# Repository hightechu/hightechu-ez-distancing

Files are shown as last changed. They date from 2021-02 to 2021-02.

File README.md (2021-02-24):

# EZ Distancing




## EZ Distancing is an Arduino project that encourages users to follow social distancing protocols
This Arduino project uses 2 Passive Infrared Sensors (PIR) and 2 Ultrasonic Distance Sensors to detect if another person is within the users 2 meter social distancing bubble. If the device detects that a person is within a 2 meter radius of the user, it will alert them, letting them know that they should move away to maintain social distancing. If the person is maintaining their social distancing, it will let them know that they are the recommended distance away from others.

## How it works

- The 2 Ultrasonic sensors measure the distance of the target object by emitting ultrasonic sound waves. The sensor determines the distance of an object by calculating the time it takes to send and receive a pulse.

- The Passive Infrared sensors measure the amount of IR light (or heat) that an object gives off. These sensors are being used to differentiate between non-living and living things. 

- When the device detects that another person is too close, it will give the user alerts via an OLED or LCD display and a LED/vibration motor.

- The DIP switches allow the user to choose which alerts they want to receive. Individual components can be turned off, like the LED or vibration motor.

## Component Usage

- Arduino Uno:
Microcontroller that will be handling all of the code, data, and inputs/outputs

- OLED or LCD Screen:
To give the user different text based alerts

- Distance Sensors:
Ultrasonic sensor that measures distance from 2cm - 400cm

- Motion Sensors:
Passive Infrared Sensor that measures 6 to 7 meters at 110 degrees

- Vibration Motor:
Vibration to physically alert the user 

- LED:
Light to visually alert the user 

- DIP switches:
This is to turn off any specific components, such as the LCD, OLED display, or vibration motor. This component is optional and wont require any changes to the code.

- Switch:
This will be used to turn the whole system on or off.

## Components List

#### All of the components used can be easily sourced on Amazon for about $100USD or $130 CAD
  - 1x Arduino R3 | [Arduino](https://store.arduino.cc/usa/arduino-uno-rev3) | [Amazon](https://amzn.to/39Mofgh) | [Arduino Datasheet](https://github.com/hightechu/hightechu-ez-distancing/blob/readme-updates/Datasheets/Arduino%20Datasheet.pdf)
  - 1x OLED Display | [Amazon](https://amzn.to/3oUkh9T) |  [OLED Datasheet](https://github.com/hightechu/hightechu-ez-distancing/blob/readme-updates/Datasheets/OLED%20Datasheet.pdf) This Diplay is also an option: [Adafruit](https://www.adafruit.com/product/1447)
  - 2x PIR Sensors | [Amazon](https://amzn.to/3jdQJ5E) | [Digikey](https://www.digikey.ca/en/products/detail/parallax-inc/555-28027/1774435?productid=1774435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) | [PIR Datasheet](https://github.com/hightechu/hightechu-ez-distancing/blob/readme-updates/Datasheets/PIR%20Datasheet.pdf)
  - 2x Ultrasonic Distance Sensors | [Amazon](https://amzn.to/3cDDKZL) | [Digikey](https://www.digikey.ca/en/products/detail/parallax-inc/28015/1774419?productid=1774419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) | [Ultrasonic Datasheet](https://github.com/hightechu/hightechu-ez-distancing/blob/readme-updates/Datasheets/Ultrasonic%20Datasheet.pdf)
  - 1x Vibration Motor | [Amazon](https://amzn.to/2O4mnXT) | [Banggood](https://usa.banggood.com/Vibration-Motor-Module-Mini-Flat-Vibrating-DC-Motor-p-1334091.html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)
  - 1x LED Light | [Amazon](https://amzn.to/2MWNaoA) | Any basic LED light will work
  - 1x 330 Ohm Resistor | [Amazon](https://amzn.to/2MNKfhM) | Any 330 ohm resistor will work
  - 1x Power Switch | [Amazon](https://amzn.to/2O3LQ3I) | This can be any type of basic switch
  - 1x DIP Switches | [Amazon](https://amzn.to/3je81Q0) | For the dipswitches, you can also use multiple normal switches
  - 1x Arduino 9v Battery Clip | [Amazon](https://amzn.to/3aAL9Gw) | This needs to be a 9V battery clip to 5.5mm barrel jack adapter
  - 1x 9 Volt Battery | [Amazon](https://amzn.to/36EQhbG) | Any 9V battery will work

 ## Diagrams | [See the Digital Circuit Here](https://www.tinkercad.com/things/4oZ3T0bb2it)
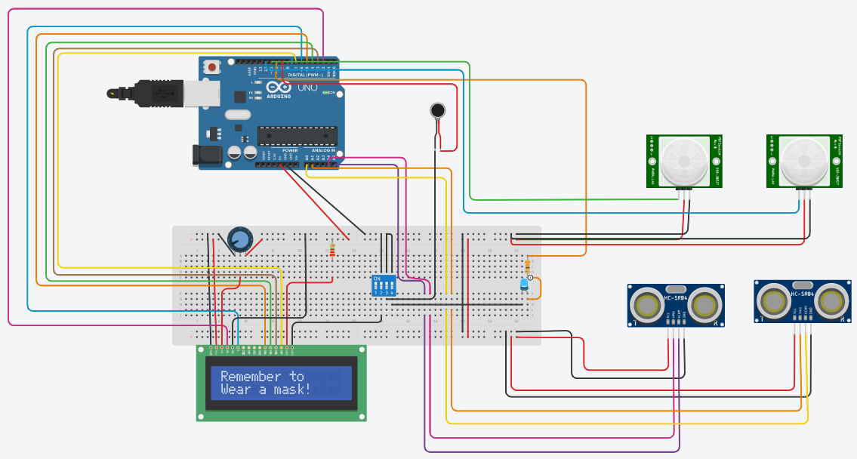
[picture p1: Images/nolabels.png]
EZ Social Distancing

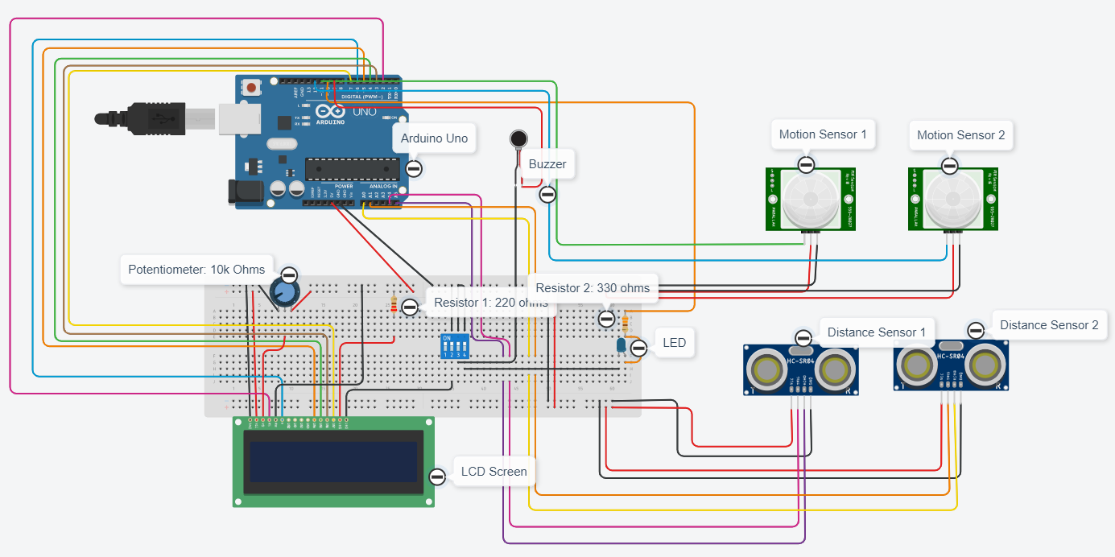
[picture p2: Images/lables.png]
EZ Social Distancing Labels


## Schematic | Drawn using [Fritzing](https://fritzing.org/)
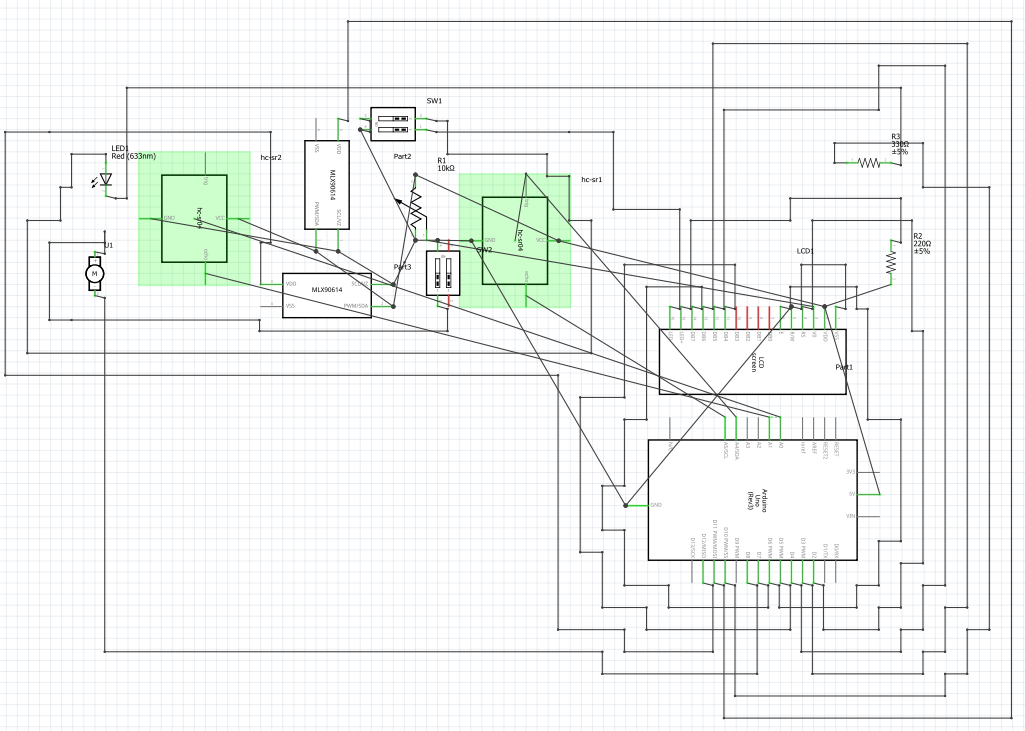
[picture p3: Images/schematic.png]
EZ Social Distancing Schematic


## Wiring List
### LCD (Note: This is for the Arduino 16x2 display. This will need the [LCD specific code](https://github.com/hightechu/hightechu-ez-distancing/blob/development/Arduino%20Code/EZ%20Social%20Distance%20(LCD16x2)/EZ%20Social%20Distance%20(LCD16x2).ino))
- GND → Ground
- VCC → Positive
- V0 → potentiometer wiper pin → Positive (5V) + Ground
- RS → Digital 2
- R/W → Ground
- E → Digital 6
- D0 → Nothing
- D1 → Nothing
- D2 → Nothing
- D3 → Nothing
- D4 → Digital 5
- D5 → Digital 4
- D6 → Digital 3
- D7 → Digital 7
- A (Anode) → 220 Ohm resistor → Positive (5V)
- K (Cathode) → Ground

### OR

### OLED (Note: This wiring list is for the OLED. This will need the [OLED specific code](https://github.com/hightechu/hightechu-ez-distancing/blob/development/Arduino%20Code/EZ%20Social%20Distance%20(OLED)/EZ%20Social%20Distance%20(OLED).ino))
- GND → Dipswitch 2 → Ground
- VCC → Positive (5V)
- SCK → Analog 4
- SDA → Analog 5

### LED:
- Cathode (Long Side) → Dipswitch 3 → Ground
- Anode (Short Side) → 330 Ohm resistor → Digital 10

### Vibration Motor:
- GND → Ground
- VCC → Positive (5V)
- IN → Digital 9

### DIP switches:
- Switch 1 (LED Resistor) → Digital 10 (This dipswitch is to turn the LED alerts on/off)
- Switch 2 (Vibration Motor In) → Digital 9 (This dipswitch is to turn the vibration alerts on/off)

### PIR Sensor 1:
- Signal → Digital 11
- Power → Positive (5V)
- GND → Ground

### PIR Sensor 2:
- Signal → Digital 12
- Power → Positive (5V)
- GND → Ground

### Ultrasonic Distance Sensor 1:
- VCC → Positive (5V)
- Trig → Analog 2
- Echo → Analog 3
- GND → Ground

### Ultrasonic Distance Sensor 2:
- VCC → Positive (5V)
- Trig → Analog 1
- Echo → Analog 0
- GND → Ground

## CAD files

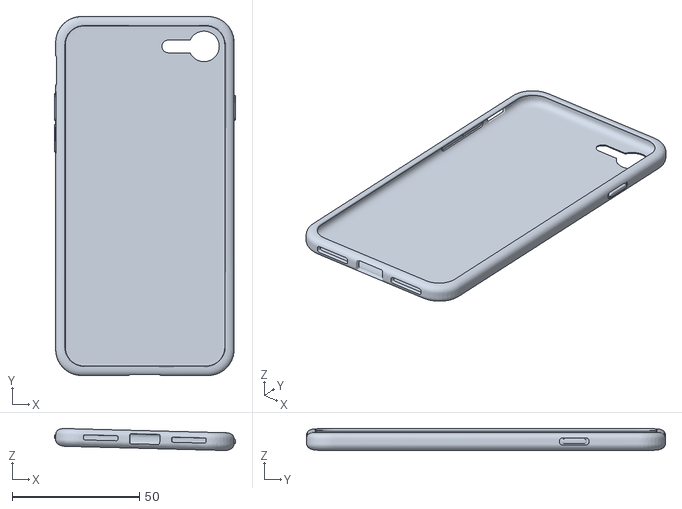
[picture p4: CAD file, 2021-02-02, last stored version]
model/Effortless Distancing - CAD.stl
71.2 x 141.0 x 8.65

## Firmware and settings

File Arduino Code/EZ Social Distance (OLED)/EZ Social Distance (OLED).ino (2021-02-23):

//Library
#include <SPI.h>
#include <Wire.h>
#include <Adafruit_GFX.h>
#include <Adafruit_SSD1306.h>

//Set up the OLED Screen
#define SCREEN_WIDTH 128
#define SCREEN_HEIGHT 32
#define OLED_RESET 4
#define SCREEN_ADDRESS 0x3C
Adafruit_SSD1306 display(SCREEN_WIDTH, SCREEN_HEIGHT, &Wire, OLED_RESET);

//Set up the PIR pins and set variables
int sensor1 = 11;
int sensor2 = 12;
int val;
int val2;

//Set up distance sensor pins
int trig2 = A2;
int echo2 = A3;
int trig1 = A1;
int echo1 = A0;

//Set up variables for the LED and vibration motor
int led = 10;
int vibration = 9;

//Give an Init variable for the Ultrasonic sensors. Using Long for less rounding errors
long duration1;
long duration2;
long distance1;
long distance2;

void setup() {
//Init OLED Screen
if(!display.begin(SSD1306_SWITCHCAPVCC, SCREEN_ADDRESS)) {
    Serial.println(F("SSD1306 allocation failed"));
    for(;;); // Don't proceed, loop forever
}//OLED

//Turn on the Serial monitor
Serial.begin(9600);  

//Setting up the PIR input pins as input
pinMode(sensor1, INPUT);
pinMode(sensor2, INPUT);

//Set up LED and vibration motor pins as output
pinMode(led, OUTPUT);
pinMode(vibration, OUTPUT);

//Power On test and reminder
display.clearDisplay();
display.setTextSize(1);
display.setTextColor(SSD1306_WHITE);
display.setCursor(0,0);
display.print("Please Remember");
display.setCursor(0,10);
display.print("To Wear A Mask!");
display.display();
digitalWrite(led, HIGH);
digitalWrite(vibration, HIGH);
delay(4000);
display.clearDisplay();
digitalWrite(led, LOW);
digitalWrite(vibration, LOW);


}//Void Setup


void loop() {

//Set an init value/variable to the PIR sensors
val = digitalRead(sensor1);
val2 = digitalRead(sensor2);

//Create a variable to tell the distance sensors how long to trigger
duration1 = readUltrasonicDistance(trig1,echo1);
duration2 = readUltrasonicDistance(trig2,echo2);

//Divide by 58 to convert distance to cm
distance1 = duration1/58;
distance2 = duration2/58;

//Print the distances to the Serial monitor, and seperate values
Serial.println(distance1);
Serial.println("----------");
Serial.println(distance2);
Serial.println(" ");
delay(100);  

//Print the ultrasonic values to the OLED
//display.clearDisplay();
display.setTextSize(1);
display.setTextColor(SSD1306_WHITE);

  
  
//If any of the PIR sensors go off AND either of the distance sensors detect a distance of >2 meters
if ((val == HIGH || val2 == HIGH) && (distance1 < 200 || distance2 < 200)) {
  delay(200);
  //Print to the OLED and alert the user
  display.clearDisplay();
  display.setCursor(0,0);
  display.print("Motion");
  display.setCursor(0,10);
  display.print("Detected");
  display.display();
  digitalWrite(led, HIGH);
  digitalWrite(vibration, HIGH);
  display.setCursor(90,0);
  display.print("1: ");
  display.setCursor(100,0);
  display.print(distance1);
  display.setCursor(90,20);
  display.print("2: ");
  display.setCursor(100,20);
  display.print(distance2);
  display.display();  
  delay(200);
  }//If

//If the above conditions are not met, do not alert the user
  else{
    delay(200);
    display.clearDisplay();
    display.setCursor(0,0);
    display.print("Nothing");
    display.setCursor(90,0);
    display.print("1: ");
    display.setCursor(100,0);
    display.print(distance1);
    display.setCursor(90,20);
    display.print("2: ");
    display.setCursor(100,20);
    display.print(distance2);
    display.display();
    delay(200);
    }//Else

//Turn off the vibration motor and LED
digitalWrite(led, LOW);
digitalWrite(vibration, LOW);
 
}//Void Loop
 
 
//FUNCTION
long readUltrasonicDistance(int triggerPin, int echoPin)//Get Values
{
  pinMode(triggerPin, OUTPUT);  // Clear the trigger
  digitalWrite(triggerPin, LOW);
  delayMicroseconds(2); //Delay by 2 microseconds to get distance
  // Sets the trigger pin to HIGH state for 10 microseconds
  digitalWrite(triggerPin, HIGH);
  delayMicroseconds(10); //Delay by 10 microseconds
  digitalWrite(triggerPin, LOW);
  pinMode(echoPin, INPUT); //Read the input
  // Reads the echo pin, and returns the sound wave travel time in microseconds
  return pulseIn(echoPin, HIGH); //Get the data from sensors
//End of function
 
 
}//Function

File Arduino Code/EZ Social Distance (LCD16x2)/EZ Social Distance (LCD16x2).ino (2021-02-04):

//Library
#include <LiquidCrystal.h>


//Setting up the pins for the LCD, buzzer, and LED
//Set up LCD layout
const int rs = 2, en = 6, d4 = 5, d5 = 4, d6 = 3, d7 = 7;
LiquidCrystal lcd(rs, en, d4, d5, d6, d7);
int sensor1 = 11;
int sensor2 = 12;
//Giving the sensors a default state / pin
int val;
int val2;
int trig1 = A4;
int echo1 = A5;
int trig2 = A1;
int echo2 = A0;

//Give an init variable for the ultrasonic sensors. Using long for less rounding errors in the distances
long duration1;
long duration2;
long distance1;
long distance2;


//Set up the buzzer and LED pins
int ledPin = 10;
int buzzerPin = 9;

//Initialize all of the pins. Setting up INPUT/OUTPUTS. 
void setup() {//Start void setup

//Setting the pins to output or input  
 pinMode(buzzerPin, OUTPUT);
 pinMode(ledPin, OUTPUT);
 pinMode(sensor1, INPUT); 
  
  
//Init LCD  
 lcd.begin(16, 2);
//Power on test/reminders
  lcd.setCursor(0,0);
  lcd.print("Remember to");
  lcd.setCursor(0,1);
  lcd.print("Wear a mask!");
  digitalWrite(ledPin, HIGH);
  digitalWrite(buzzerPin, HIGH);
  delay(5000);
  lcd.clear();
//Turn on serial monitor  
  Serial.begin(9600);
 
  
}//End of void setup

void loop() {//Start void loop
 
//Set an init value/variable to the PIR sensors  
  val = digitalRead(sensor1);
  val2 = digitalRead(sensor2);
  
//Create a variable to tell the distance sensors how long to trigger
  duration1 = readUltrasonicDistance(trig1,echo1);
  duration2 = readUltrasonicDistance(trig2,echo2);
  
//Divide by 58 to convert distance to cm  
  distance1 = duration1/58;
  distance2 = duration2/58;
  
//Print the distances to the Serial, and seperate the for readability  
  Serial.println(distance1);
  Serial.println("----------");
  Serial.println(distance2);
  Serial.println(" ");
  delay(200);
  
  //If any of the PIR sensors go off AND either of the distance sensors detect a distance of >2 meters
  if ((val == HIGH || val2 == HIGH) && (distance1 < 200 || distance2 < 200)) {
    delay(200);
//Printing to the LCD/serial
    lcd.clear();
    lcd.setCursor(0,0);
//The LCD on tinkercad is too small. Actual message will read "You are not social distancing! please move away."    
    lcd.print("Motion");
    lcd.setCursor(0,1);
    lcd.print("Detected");
//Turn on the LED and buzzer
    digitalWrite(ledPin, HIGH);
    digitalWrite(buzzerPin, HIGH);
    delay(200);
    
  }//End of high if
  
  
//If the above conditions are not met, do not alert the user
  else{
    delay(200);
//Printing to the LCD/serial
    lcd.clear();
//Actual message will read "You are >2m away. Thank you!"    
    lcd.print("Nothing");
//Turn off LED and buzzer and add delay
    delay(200);
    
  }//End of else  
  
  
//Turn off the LED/Buzzer  
digitalWrite(ledPin, LOW);
digitalWrite(buzzerPin, LOW);
   
  
    }//End of void loop

//FUNCTION
long readUltrasonicDistance(int triggerPin, int echoPin)//Get Values
{
  pinMode(triggerPin, OUTPUT);  // Clear the trigger
  digitalWrite(triggerPin, LOW);
  delayMicroseconds(2); //Delay by 2 microseconds to get distance
  // Sets the trigger pin to HIGH state for 10 microseconds
  digitalWrite(triggerPin, HIGH);
  delayMicroseconds(10); //Delay by 10 microseconds
  digitalWrite(triggerPin, LOW);
  pinMode(echoPin, INPUT); //Read the input
  // Reads the echo pin, and returns the sound wave travel time in microseconds
  return pulseIn(echoPin, HIGH); //Get the data from sensors
//End of function


}//End of void loop

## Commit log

2021-02-02 effortlessdistancing
    Project Inspiration
    [Effortless Distancing - CAD.stl, Effortless Distancing - Circuit.brd]
2021-02-02 Preparation of Repository
    Preparation of respository for new iteration.
    [Effortless Distancing - CAD.stl, Effortless Distancing - Circuit.brd]
2021-02-04 Added the Arduino sketch
    This is the completed code for the digital prototype.
2021-02-04 Digital Prototype
    Added an image of the digital prototype for the README
2021-02-04 Diagrams
    Added images of the digital prototype for the README
2021-02-09 Development (#4)
    * Readme updates (#2)
    * Updating Images
    * Updating Images
    * Updated images
    Added the dipswitches
    * Updated readme
    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
2021-02-10 Development (#8)
    added the dipswitches to the diagrams
    * Added schematic
    Added the schematic for the readme
    * added the schematic
    added the dipswitches to the diagrams
    * Added schematic
    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
2021-02-23 Readme updates (#16)
    * Added link to tinkercad
    * Added datasheets to some components
    * Added downloads of the datasheets
    Added downloads to stay in the repo
    * Updated datasheets to the folder on th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
2021-02-24 Development (#18)
    * Updated datasheets to the folder on the r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

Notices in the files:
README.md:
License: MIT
